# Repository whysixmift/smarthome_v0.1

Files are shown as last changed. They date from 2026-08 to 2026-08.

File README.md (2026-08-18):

# Smart Home ESP32 Board

I wanted to control lights and appliances in my room over Wi-Fi without having loose relay modules, breadboards, and 220V AC wires floating around my desk. Wiring loose AC mains on a breadboard felt super unsafe, so I designed this 4-channel relay board in KiCad.

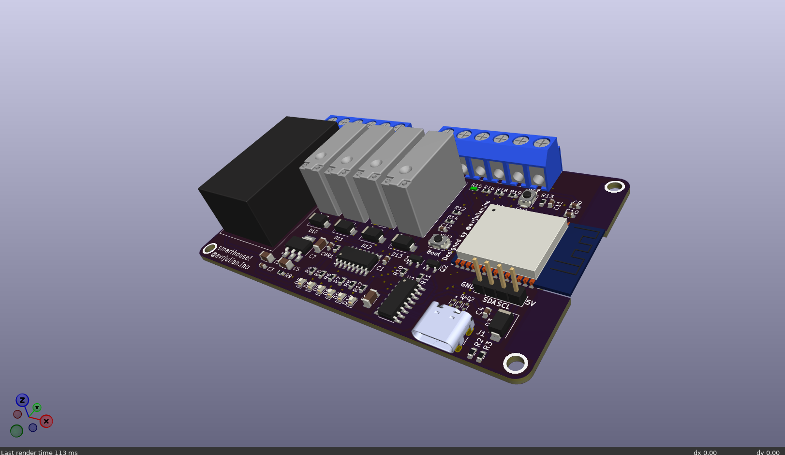
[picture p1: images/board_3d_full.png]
3D view

*3D render of the board in KiCad*

## Features

- **ESP32-WROOM-32**: Main microcontroller for Wi-Fi control.
- **4 Relays**: Switches 4 separate AC/DC loads (5V 5A relays driven by a ULN2003A driver chip).
- **Onboard Power**: Hi-Link HLK-PM01 takes 100-240V AC input and outputs 5V DC, so I don't need an external power adapter. An AMS1117-3.3 steps it down to 3.3V for the ESP32.
- **USB-C Flashing**: Built-in CH340C serial chip with auto-reset circuit so code uploads straight over USB-C.
- **Wall Switch Inputs**: Screw terminal `J3` lets me plug in external wall switches.
- **I2C Header**: 4-pin header `J4` for extra I2C sensors if needed later.

## Pin Map

| ESP32 Pin | Connected To | What It Does |
| :--- | :--- | :--- |
| GPIO 25 | Relay 1 + LED D6 | Relay 1 Output |
| GPIO 23 | Relay 2 + LED D7 | Relay 2 Output |
| GPIO 19 | Relay 3 + LED D8 | Relay 3 Output |
| GPIO 18 | Relay 4 + LED D9 | Relay 4 Output |
| GPIO 13 | Terminal J3 Pin 1 | Wall Switch 1 Input |
| GPIO 12 | Terminal J3 Pin 2 | Wall Switch 2 Input |
| GPIO 27 | Terminal J3 Pin 3 | Wall Switch 3 Input |
| GPIO 14 | Terminal J3 Pin 4 | Wall Switch 4 Input |
| GPIO 21 | Header J4 Pin 3 | I2C SDA |
| GPIO 22 | Header J4 Pin 4 | I2C SCL |
| GPIO 2 | LED D5 | Status LED |
| GPIO 0 | Button SW2 | Boot button |
| EN | Button SW1 | Reset button |

## Board Pictures

### Schematic
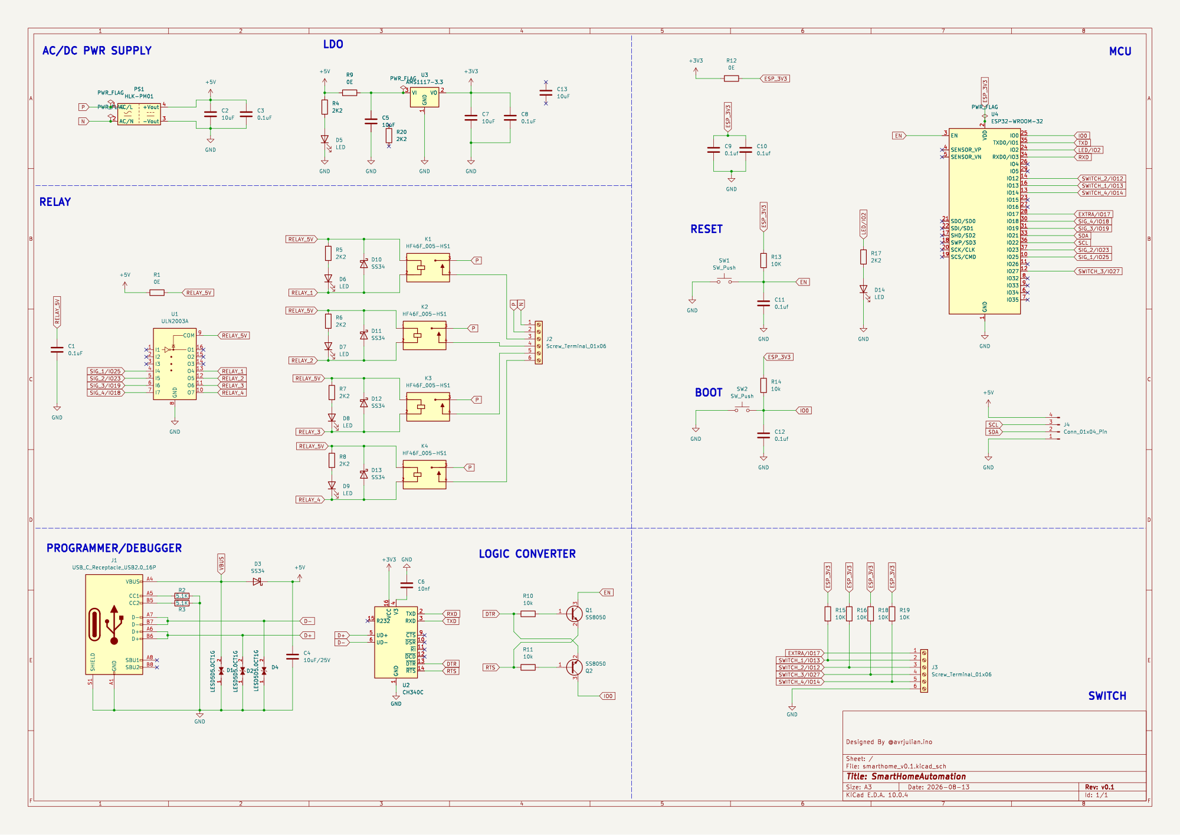
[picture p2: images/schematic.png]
Schematic

*KiCad schematic*

### PCB
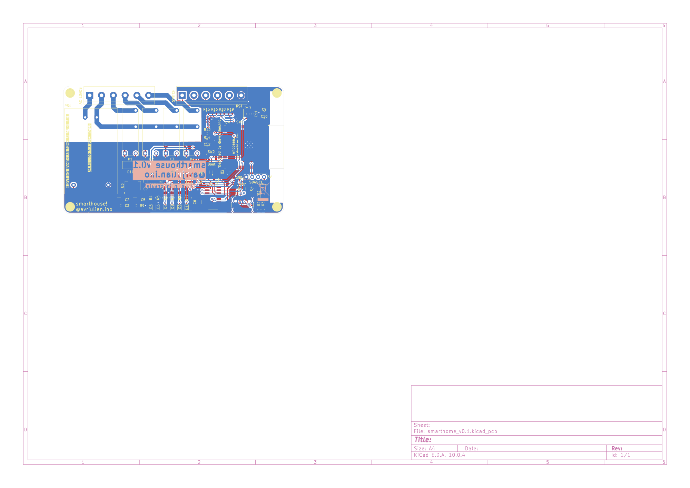
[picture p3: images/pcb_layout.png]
PCB Layout

*PCB layout*

### Details
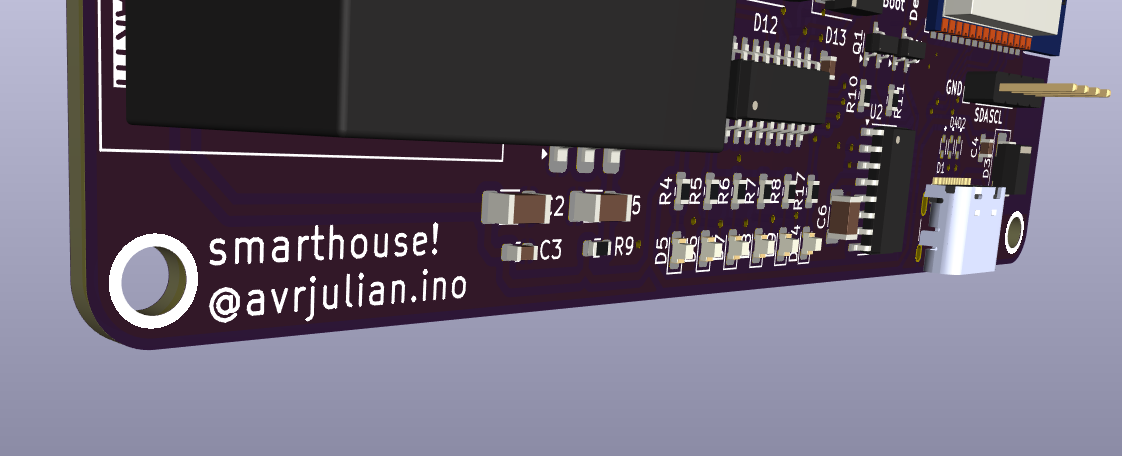
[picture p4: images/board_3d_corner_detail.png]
LEDs

*Status LEDs and passives*

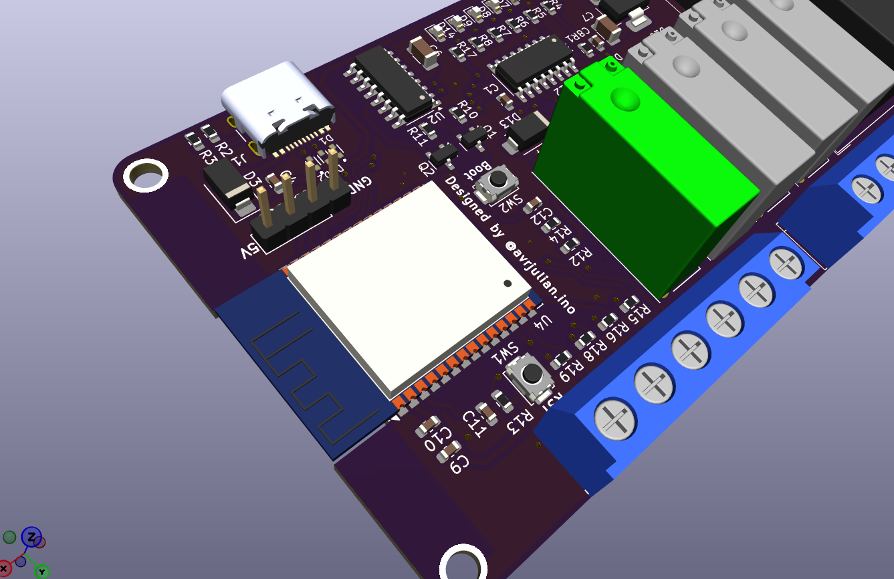
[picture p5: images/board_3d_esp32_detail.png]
ESP32

*ESP32 and USB-C section*

## Firmware

Firmware is inside the `firmware/` folder. It uses PlatformIO with Arduino framework and simple FreeRTOS tasks to read the wall switches and toggle relays.

To flash:
1. Open `firmware/` in VS Code with PlatformIO.
2. Plug in the board over USB-C.
3. Run `pio run -t upload`.

## BOM & Cost

Full component list with purchase links is in [`BOM.csv`](BOM.csv). Total cost is around **$9.36**.

| Part | Qty | Link |
| :--- | :---: | :--- |
| ESP32-WROOM-32 | 1 | [LCSC C82899](https://www.lcsc.com/product-detail/WiFi-Modules_Espressif-Systems-ESP32-WROOM-32-N4_C82899.html) |
| HF46F 5V Relays | 4 | [LCSC C38573](https://www.lcsc.com/product-detail/Relays_Hongfa-America-HF46F-005-HS1_C38573.html) |
| ULN2003A Driver | 1 | [LCSC C14881](https://www.lcsc.com/product-detail/Darlington-Transistor-Arrays_STMicroelectronics-ULN2003D1013TR_C14881.html) |
| HLK-PM01 AC-DC | 1 | [LCSC C209743](https://www.lcsc.com/product-detail/Power-Modules_Hi-Link-HLK-PM01_C209743.html) |
| CH340C Serial | 1 | [LCSC C84681](https://www.lcsc.com/product-detail/USB-Drivers-Receivers-Transceivers_WCH-Jiangsu-Qinheng-Microelec-CH340C_C84681.html) |
| USB-C Connector | 1 | [LCSC C165948](https://www.lcsc.com/product-detail/USB-Connectors_HCTL-HC-TYPE-C-16P-01A_C165948.html) |
| Screw Terminals | 2 | [LCSC C8456](https://www.lcsc.com/product-detail/Pluggable-System-Terminal-Block_C8456.html) |

## Notes / Honest Status

- All ERC and DRC checks in KiCad pass without errors, and firmware builds fine with `pio run`.
- I haven't tested the firmware on the physical PCB yet since the board hasn't arrived.
- Be careful with AC mains (100-240V) near `PS1` and terminal `J2`. Keep it in an insulated case.

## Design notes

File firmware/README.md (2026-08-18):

# ESP32 Smart Home Controller Firmware

This directory contains the firmware for the **Smart Home ESP32 4-Channel Relay Controller** PCB.

## Features

* **4-Channel Relay Control**: Controls four 5V mechanical relays on GPIO 25, 23, 19, and 18 via ULN2003A driver.
* **External Switch Handling**: Debounced digital input handlers for wall switches connected to screw terminal `J3` (GPIO 13, 12, 27, 14).
* **FreeRTOS Multi-Tasking**: Separate tasks for input debouncing and status LED heartbeat animation.
* **Serial Debugging**: Clean boot sequence messages at 115200 baud.

## Hardware GPIO Mapping

| Function | ESP32 GPIO | Net Name | Description |
| :--- | :--- | :--- | :--- |
| **Relay 1** | GPIO 25 | `SIG_1/IO25` | Output 1 (Relay K1 + Status LED D6) |
| **Relay 2** | GPIO 23 | `SIG_2/IO23` | Output 2 (Relay K2 + Status LED D7) |
| **Relay 3** | GPIO 19 | `SIG_3/IO19` | Output 3 (Relay K3 + Status LED D8) |
| **Relay 4** | GPIO 18 | `SIG_4/IO18` | Output 4 (Relay K4 + Status LED D9) |
| **Switch 1** | GPIO 13 | `SWITCH_1/IO13` | Terminal Block J3 Pin 1 |
| **Switch 2** | GPIO 12 | `SWITCH_2/IO12` | Terminal Block J3 Pin 2 |
| **Switch 3** | GPIO 27 | `SWITCH_3/IO27` | Terminal Block J3 Pin 3 |
| **Switch 4** | GPIO 14 | `SWITCH_4/IO14` | Terminal Block J3 Pin 4 |
| **Status LED**| GPIO 2 | `LED/IO2` | Onboard Indicator LED D5 |

## Compilation & Flashing

### Using PlatformIO

```bash
pio run -t upload
```

### Using Arduino IDE

1. Open `firmware.ino` in Arduino IDE.
2. Select Board: **ESP32 Dev Module**.
3. Click **Upload**.

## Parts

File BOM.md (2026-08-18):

# Bill of Materials (BOM) - Smart Home ESP32 Controller

Below is the complete component list for the Smart Home ESP32 4-Channel Relay PCB with direct purchase links (LCSC) and datasheet references.

| Reference | Component | Package / Footprint | Qty | Function | Part Number / Purchase Link | Datasheet |
| :--- | :--- | :--- | :---: | :--- | :--- | :--- |
| `U4` | ESP32-WROOM-32 | ESP32-WROOM-32 SMD | 1 | Microcontroller (Wi-Fi + BLE) | [LCSC C82899](https://www.lcsc.com/product-detail/WiFi-Modules_Espressif-Systems-ESP32-WROOM-32-N4_C82899.html) | [Datasheet](https://www.espressif.com/sites/default/files/documentation/esp32-wroom-32_datasheet_en.pdf) |
| `PS1` | HLK-PM01 | Converter_ACDC:HLK-PMxx | 1 | AC 100-240V to DC 5V 3W Power Module | [LCSC C209743](https://www.lcsc.com/product-detail/Power-Modules_Hi-Link-HLK-PM01_C209743.html) | [Datasheet](http://www.hlktech.net/product_detail.php?id=38) |
| `U3` | AMS1117-3.3 | SOT-223-3 | 1 | 3.3V 1A LDO Voltage Regulator | [LCSC C6186](https://www.lcsc.com/product-detail/Linear-Voltage-Regulators-LDO_Advanced-Monolithic-Systems-AMS1117-3-3_C6186.html) | [Datasheet](http://www.advanced-monolithic.com/pdf/ds1117.pdf) |
| `U1` | ULN2003A | SOIC-16 | 1 | 7-NPN Darlington Transistor Array | [LCSC C14881](https://www.lcsc.com/product-detail/Darlington-Transistor-Arrays_STMicroelectronics-ULN2003D1013TR_C14881.html) | [Datasheet](https://www.ti.com/lit/ds/symlink/uln2003a.pdf) |
| `U2` | CH340C | SOIC-16 | 1 | USB-to-UART Serial Converter | [LCSC C84681](https://www.lcsc.com/product-detail/USB-Drivers-Receivers-Transceivers_WCH-Jiangsu-Qinheng-Microelec-CH340C_C84681.html) | [Datasheet](https://www.sparkfun.com/datasheets/IC/CH340DS1.PDF) |
| `K1, K2, K3, K4` | HF46F-005-HS1 | RELAY_HF46F_005-HS1 | 4 | 5V Coil / 5A 250VAC Mini Power Relays | [LCSC C38573](https://www.lcsc.com/product-detail/Relays_Hongfa-America-HF46F-005-HS1_C38573.html) | [Datasheet](https://www.hongfa.com/Product/PDF/HF46F_en.pdf) |
| `J1` | USB_C_Receptacle_16P | USB-C 16-Pin SMD | 1 | USB Type-C Power & Programming Port | [LCSC C165948](https://www.lcsc.com/product-detail/USB-Connectors_HCTL-HC-TYPE-C-16P-01A_C165948.html) | [Datasheet](https://www.lcsc.com/product-detail/USB-Connectors_HCTL-HC-TYPE-C-16P-01A_C165948.html) |
| `J2, J3` | Screw_Terminal_01x06 | 6-Pin 5.08mm Pitch | 2 | High-Voltage & Relay Screw Terminals | [LCSC C8456](https://www.lcsc.com/product-detail/Pluggable-System-Terminal-Block_C8456.html) | [Datasheet](https://www.lcsc.com/product-detail/Pluggable-System-Terminal-Block_C8456.html) |
| `J4` | Conn_01x04_Pin | PinHeader 1x4 2.54mm | 1 | I2C Header (5V, GND, SDA, SCL) | [LCSC C37207](https://www.lcsc.com/product-detail/Pin-Header-Female-Header_C37207.html) | [Datasheet](https://www.lcsc.com/product-detail/Pin-Header-Female-Header_C37207.html) |
| `Q1, Q2` | SS8050 | SOT-23 | 2 | NPN BJT Transistors (Auto-Reset) | [LCSC C2146](https://www.lcsc.com/product-detail/Bipolar-Transistors-BJT_SS8050_C2146.html) | [Datasheet](https://datasheet.lcsc.com/lcsc/1810171731_MCC-SS8050-TP_C2146.pdf) |
| `D1, D2, D4` | LESD5D5.0CT1G | SOD-523 | 3 | ESD Protection Diodes (5V) | [LCSC C80415](https://www.lcsc.com/product-detail/TVS_LESD5D5-0CT1G_C80415.html) | [Datasheet](https://datasheet.lcsc.com/lcsc/1811061935_LRC-Leshan-Radio-LESD5D5-0CT1G_C80415.pdf) |
| `D3, D10-D13` | SS34 | SMA (DO-214AC) | 5 | 3A 40V Schottky Diodes | [LCSC C1592](https://www.lcsc.com/product-detail/Schottky-Barrier-Diodes-SBD_SS34_C1592.html) | [Datasheet](https://datasheet.lcsc.com/lcsc/1810181519_MS-SS34_C1592.pdf) |
| `D5-D9, D14` | LED Green / Red | 0603 SMD | 6 | Status & Relay Output LEDs | [LCSC C72043](https://www.lcsc.com/product-detail/Light-Emitting-Diodes-LED_C72043.html) | [Datasheet](https://datasheet.lcsc.com/lcsc/1811151441_Foshan-NationStar-Optoelectronics-NCD0603G1_C72043.pdf) |
| `SW1, SW2` | SKRK / Tactile | 3x6mm SMD Pushbutton | 2 | Reset & Boot Tactile Switches | [LCSC C318884](https://www.lcsc.com/product-detail/Tactile-Switches_C318884.html) | [Datasheet](https://datasheet.lcsc.com/lcsc/1912251636_ALPS-Electric-SKRKAEE010_C318884.pdf) |
| `C1, C3, C8-C12` | 0.1uF 50V | 0603 SMD | 7 | Decoupling Capacitors | [LCSC C14663](https://www.lcsc.com/product-detail/Multilayer-Ceramic-Capacitors-MLCC-SMD-SMT_C14663.html) | [Datasheet](https://datasheet.lcsc.com/lcsc/1811141214_YAGEO-CC0603KRX7R9BB104_C14663.pdf) |
| `C2, C5, C7` | 10uF 25V | 1206 SMD | 3 | Filter Capacitors | [LCSC C13585](https://www.lcsc.com/product-detail/Multilayer-Ceramic-Capacitors-MLCC-SMD-SMT_C13585.html) | [Datasheet](https://datasheet.lcsc.com/lcsc/1811141416_YAGEO-CC1206MKX5R8BB106_C13585.pdf) |
| `C4` | 10uF 25V | 0603 SMD | 1 | Power Line Filter Capacitor | [LCSC C19702](https://www.lcsc.com/product-detail/Multilayer-Ceramic-Capacitors-MLCC-SMD-SMT_C19702.html) | [Datasheet](https://datasheet.lcsc.com/lcsc/1811141416_YAGEO-CC0603KRX5R8BB106_C19702.pdf) |
| `C6` | 10nF 50V | 1206 SMD | 1 | Noise Suppression Capacitor | [LCSC C1588](https://www.lcsc.com/product-detail/Multilayer-Ceramic-Capacitors-MLCC-SMD-SMT_C1588.html) | [Datasheet](https://datasheet.lcsc.com/lcsc/1811141214_YAGEO-CC1206KRX7R9BB103_C1588.pdf) |
| `R1, R9, R12` | 0Ω | 0603 SMD | 3 | Zero-Ohm Jumper Resistors | [LCSC C21189](https://www.lcsc.com/product-detail/Chip-Resistor-Surface-Mount_C21189.html) | [Datasheet](https://datasheet.lcsc.com/lcsc/1811141214_Uniroyal-Elec-0603WAF0000T5E_C21189.pdf) |
| `R2, R3` | 5.1kΩ 1% | 0603 SMD | 2 | USB-C CC Line Pull-down Resistors | [LCSC C23186](https://www.lcsc.com/product-detail/Chip-Resistor-Surface-Mount_C23186.html) | [Datasheet](https://datasheet.lcsc.com/lcsc/1811141214_Uniroyal-Elec-0603WAF5101T5E_C23186.pdf) |
| `R4-R8, R17` | 2.2kΩ 1% | 0603 SMD | 6 | LED Current Limiting Resistors | [LCSC C4190](https://www.lcsc.com/product-detail/Chip-Resistor-Surface-Mount_C4190.html) | [Datasheet](https://datasheet.lcsc.com/lcsc/1811141214_Uniroyal-Elec-0603WAF2201T5E_C4190.pdf) |
| `R10, R11, R13-R16, R18, R19` | 10kΩ 1% | 0603 SMD | 8 | Pull-Up / Pull-Down Resistors | [LCSC C25804](https://www.lcsc.com/product-detail/Chip-Resistor-Surface-Mount_C25804.html) | [Datasheet](https://datasheet.lcsc.com/lcsc/1811141214_Uniroyal-Elec-0603WAF1002T5E_C25804.pdf) |

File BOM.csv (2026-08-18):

Component | Quantity | Specification / Part Number | Purpose | Purchase Link | Unit Price ($) | Total Price ($)
ESP32-WROOM-32 | 1 | ESP32-WROOM-32-N4 4MB Flash | Microcontroller (Wi-Fi + BLE) | https://www.lcsc.com/product-detail/WiFi-Modules_Espressif-Systems-ESP32-WROOM-32-N4_C82899.html | 2.75 | 2.75
Hongfa / Songle 5V Relay | 4 | HF46F-005-HS1 5V 5A Mini Power Relay | 5V Mechanical Relays (K1-K4) | https://www.lcsc.com/product-detail/Relays_Hongfa-America-HF46F-005-HS1_C38573.html | 0.45 | 1.80
ULN2003A | 1 | ULN2003ADR SOIC-16 | 7-NPN Darlington Relay Driver IC | https://www.lcsc.com/product-detail/Darlington-Transistor-Arrays_STMicroelectronics-ULN2003D1013TR_C14881.html | 0.18 | 0.18
SSD1306 OLED Display | 1 | 0.96 inch 128x64 I2C OLED Module | Local Display Interface (J4 Header) | https://www.lcsc.com/product-detail/OLED-Displays-Modules_KMR-KMR-0-96-OLED-W_C2836248.html | 1.85 | 1.85
Tactile Push Buttons | 2 | 3x6mm SMD Tactile Switch (SKRK) | Reset (SW1) and Boot (SW2) | https://www.lcsc.com/product-detail/Tactile-Switches_C318884.html | 0.05 | 0.10
HLK-PM01 | 1 | 100-240V AC to 5V DC 3W | Onboard Step-down AC-DC Power Module | https://www.lcsc.com/product-detail/Power-Modules_Hi-Link-HLK-PM01_C209743.html | 2.80 | 2.80
AMS1117-3.3 | 1 | SOT-223 3.3V 1A LDO | Linear Voltage Regulator | https://www.lcsc.com/product-detail/Linear-Voltage-Regulators-LDO_Advanced-Monolithic-Systems-AMS1117-3-3_C6186.html | 0.08 | 0.08
CH340C | 1 | SOIC-16 USB-to-UART Bridge | USB Serial Converter IC | https://www.lcsc.com/product-detail/USB-Drivers-Receivers-Transceivers_WCH-Jiangsu-Qinheng-Microelec-CH340C_C84681.html | 0.32 | 0.32
USB Type-C Connector | 1 | 16-Pin SMD Type-C Receptacle | USB Power & Programming Port (J1) | https://www.lcsc.com/product-detail/USB-Connectors_HCTL-HC-TYPE-C-16P-01A_C165948.html | 0.15 | 0.15
Screw Terminal Blocks | 2 | 6-Pin 5.08mm Pitch Terminal Block | High-Voltage AC & Relay Terminals (J2 J3) | https://www.lcsc.com/product-detail/Pluggable-System-Terminal-Block_C8456.html | 0.35 | 0.70
Pin Header 1x4 | 1 | 2.54mm Female Header 4-Pin | I2C OLED Connection Header (J4) | https://www.lcsc.com/product-detail/Pin-Header-Female-Header_C37207.html | 0.06 | 0.06
SS8050 NPN Transistor | 2 | SOT-23 NPN BJT | Auto-Reset Circuit (Q1 Q2) | https://www.lcsc.com/product-detail/Bipolar-Transistors-BJT_SS8050_C2146.html | 0.02 | 0.04
LESD5D5.0CT1G TVS Diode | 3 | SOD-523 ESD Protection Diode | ESD Protection for USB/Reset (D1 D2 D4) | https://www.lcsc.com/product-detail/TVS_LESD5D5-0CT1G_C80415.html | 0.03 | 0.09
SS34 Schottky Diode | 5 | SMA DO-214AC 3A 40V | Reverse Voltage & Flyback Diodes (D3 D10-D13) | https://www.lcsc.com/product-detail/Schottky-Barrier-Diodes-SBD_SS34_C1592.html | 0.04 | 0.20
SMD LEDs | 6 | 0603 Green/Red SMD LED | Power & Relay Status LEDs (D5-D9 D14) | https://www.lcsc.com/product-detail/Light-Emitting-Diodes-LED_C72043.html | 0.01 | 0.06
SMD Resistors (Assorted) | 18 | 0603 SMD Resistors (0Ω 5.1kΩ 2.2kΩ 10kΩ) | Pull-up / Pull-down / LED Limiting (R1-R19) | https://www.lcsc.com/product-detail/Chip-Resistor-Surface-Mount_C25804.html | 0.005 | 0.09
SMD Capacitors (Assorted) | 12 | 0603 / 1206 MLCC (0.1uF 10uF 10nF) | Filter & Decoupling Capacitors (C1-C12) | https://www.lcsc.com/product-detail/Multilayer-Ceramic-Capacitors-MLCC-SMD-SMT_C14663.html | 0.01 | 0.12
TOTAL COST |  |  |  |  |  | $11.21

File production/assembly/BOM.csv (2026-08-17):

Comment | Designator | Footprint | Quantity
0.1uF | C1 | Capacitor_SMD:C_0603_1608Metric | 1
10uF | C2 | Capacitor_SMD:C_1206_3216Metric | 1
0.1uF | C3 | Capacitor_SMD:C_0603_1608Metric | 1
10uF/25V | C4 | Capacitor_SMD:C_0603_1608Metric | 1
10uF | C5 | Capacitor_SMD:C_1206_3216Metric | 1
10nf | C6 | Capacitor_SMD:C_1206_3216Metric | 1
10uF | C7 | Capacitor_SMD:C_1206_3216Metric | 1
0.1uF | C8 | Capacitor_SMD:C_0603_1608Metric | 1
0.1uf | C9 | Capacitor_SMD:C_0603_1608Metric | 1
0.1uf | C10 | Capacitor_SMD:C_0603_1608Metric | 1
0.1uf | C11 | Capacitor_SMD:C_0603_1608Metric | 1
0.1uf | C12 | Capacitor_SMD:C_0603_1608Metric | 1
LESD5D5.0CT1G | D1 | LESD5D5.0CT1G:TVS_LESD5D5.0CT1G | 1
LESD5D5.0CT1G | D2 | LESD5D5.0CT1G:TVS_LESD5D5.0CT1G | 1
SS34 | D3 | Diode_SMD:D_SMA | 1
LESD5D5.0CT1G | D4 | LESD5D5.0CT1G:TVS_LESD5D5.0CT1G | 1
LED | D5 | LED_SMD:LED_0603_1608Metric | 1
LED | D6 | LED_SMD:LED_0603_1608Metric | 1
LED | D7 | LED_SMD:LED_0603_1608Metric | 1
LED | D8 | LED_SMD:LED_0603_1608Metric | 1
LED | D9 | LED_SMD:LED_0603_1608Metric | 1
SS34 | D10 | Diode_SMD:D_SMA | 1
SS34 | D11 | Diode_SMD:D_SMA | 1
SS34 | D12 | Diode_SMD:D_SMA | 1
SS34 | D13 | Diode_SMD:D_SMA | 1
LED | D14 | LED_SMD:LED_0603_1608Metric | 1
USB_C_Receptacle_USB2.0_16P | J1 | lib:USB_C_Receptacle_HCTL_HC-TYPE-C-16P-01A | 1
Screw_Terminal_01x06 | J2 | lib:TerminalBlock_bornier-6_P5.08mm | 1
Screw_Terminal_01x06 | J3 | lib:TerminalBlock_bornier-6_P5.08mm | 1
Conn_01x04_Pin | J4 | Connector_PinHeader_2.54mm:PinHeader_1x04_P2.54mm_Vertical | 1
HF46F_005-HS1 | K1 | HF46F_005-HS1:RELAY_HF46F_005-HS1 | 1
HF46F_005-HS1 | K2 | HF46F_005-HS1:RELAY_HF46F_005-HS1 | 1
HF46F_005-HS1 | K3 | HF46F_005-HS1:RELAY_HF46F_005-HS1 | 1
HF46F_005-HS1 | K4 | HF46F_005-HS1:RELAY_HF46F_005-HS1 | 1
HLK-PM01 | PS1 | Converter_ACDC:Converter_ACDC_Hi-Link_HLK-PMxx | 1
SS8050 | Q1 | Package_TO_SOT_SMD:SOT-23 | 1
SS8050 | Q2 | Package_TO_SOT_SMD:SOT-23 | 1
0E | R1 | Resistor_SMD:R_0603_1608Metric | 1
5.1K | R2 | Resistor_SMD:R_0603_1608Metric | 1
5.1K | R3 | Resistor_SMD:R_0603_1608Metric | 1
2K2 | R4 | Resistor_SMD:R_0603_1608Metric | 1
2K2 | R5 | Resistor_SMD:R_0603_1608Metric | 1
2K2 | R6 | Resistor_SMD:R_0603_1608Metric | 1
2K2 | R7 | Resistor_SMD:R_0603_1608Metric | 1
2K2 | R8 | Resistor_SMD:R_0603_1608Metric | 1
0E | R9 | Resistor_SMD:R_0603_1608Metric | 1
10k | R10 | Resistor_SMD:R_0603_1608Metric | 1
10k | R11 | Resistor_SMD:R_0603_1608Metric | 1
0E | R12 | Resistor_SMD:R_0603_1608Metric | 1
10K | R13 | Resistor_SMD:R_0603_1608Metric | 1
10k | R14 | Resistor_SMD:R_0603_1608Metric | 1
10K | R15 | Resistor_SMD:R_0603_1608Metric | 1
10K | R16 | Resistor_SMD:R_0603_1608Metric | 1
2K2 | R17 | Resistor_SMD:R_0603_1608Metric | 1
10K | R18 | Resistor_SMD:R_0603_1608Metric | 1
10K | R19 | Resistor_SMD:R_0603_1608Metric | 1
SW_Push | SW1 | Button_Switch_SMD:SW_Push_SPST_NO_Alps_SKRK | 1
SW_Push | SW2 | Button_Switch_SMD:SW_Push_SPST_NO_Alps_SKRK | 1
ULN2003A | U1 | Package_SO:SOIC-16_3.9x9.9mm_P1.27mm | 1
CH340C | U2 | Package_SO:SOIC-16_3.9x9.9mm_P1.27mm | 1
AMS1117-3.3 | U3 | Package_TO_SOT_SMD:SOT-223-3_TabPin2 | 1
ESP32-WROOM-32 | U4 | RF_Module:ESP32-WROOM-32 | 1

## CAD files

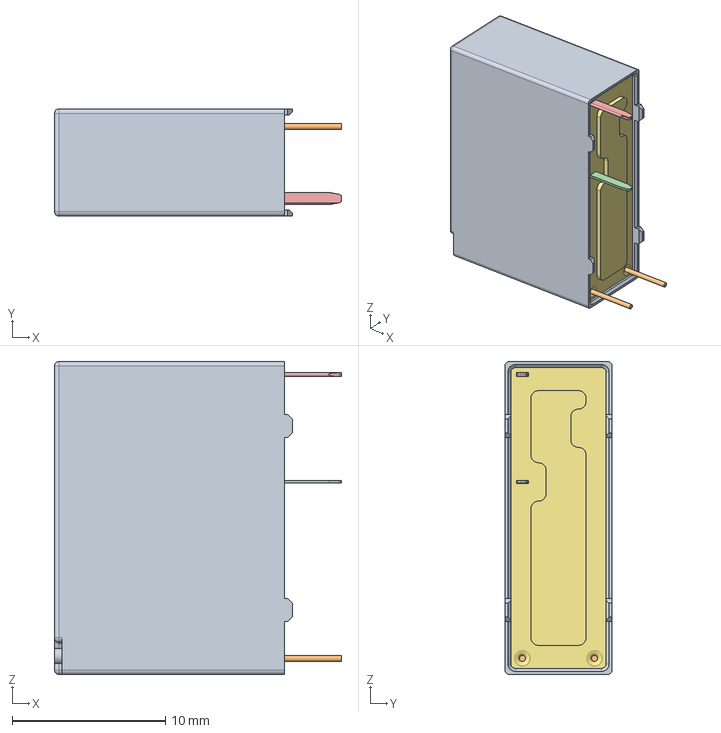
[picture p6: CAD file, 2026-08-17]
3D/189276954-3-hf46f/HF46F.stp
18.7 x 7.00 x 20.4 mm

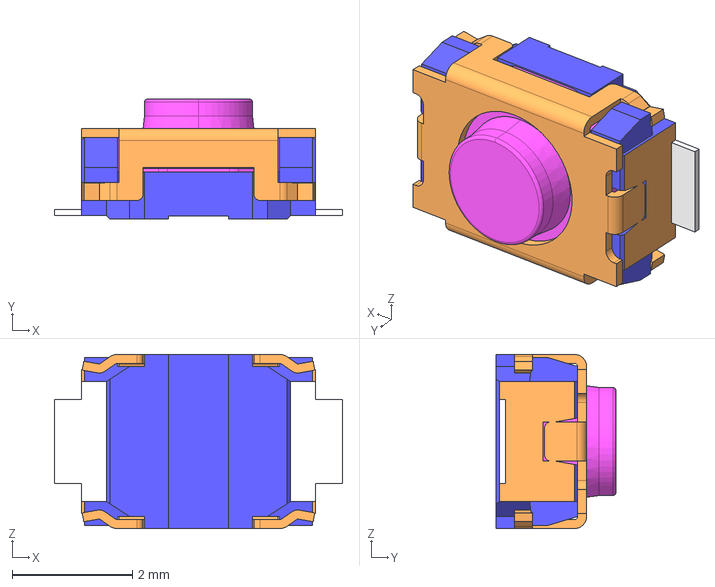
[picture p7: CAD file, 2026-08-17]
3D/skrkaee010.stp
4.80 x 2.00 x 2.90 mm

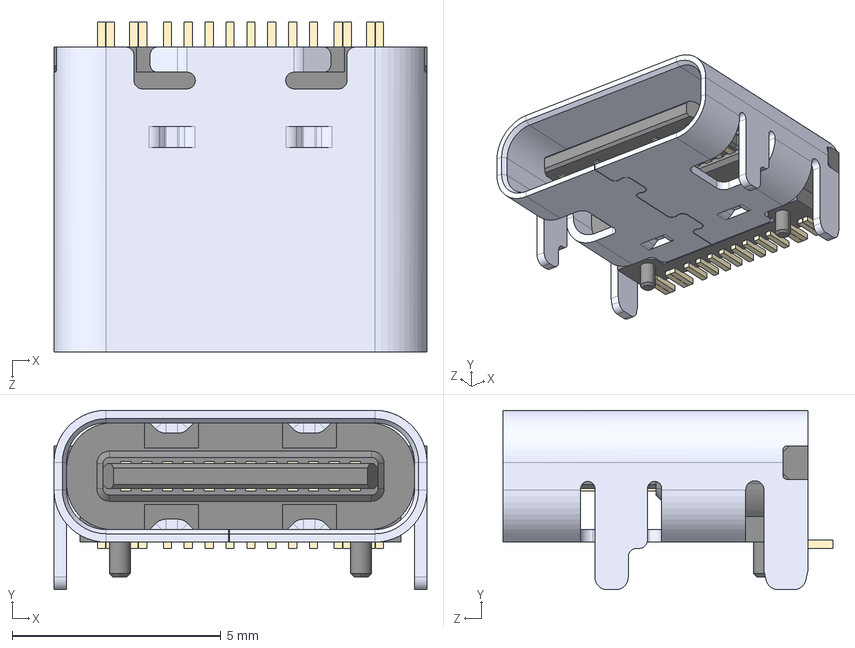
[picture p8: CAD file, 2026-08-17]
3D/TYPE-C-31-M-12--3DModel-STEP-56544.step
8.94 x 4.30 x 7.90 mm

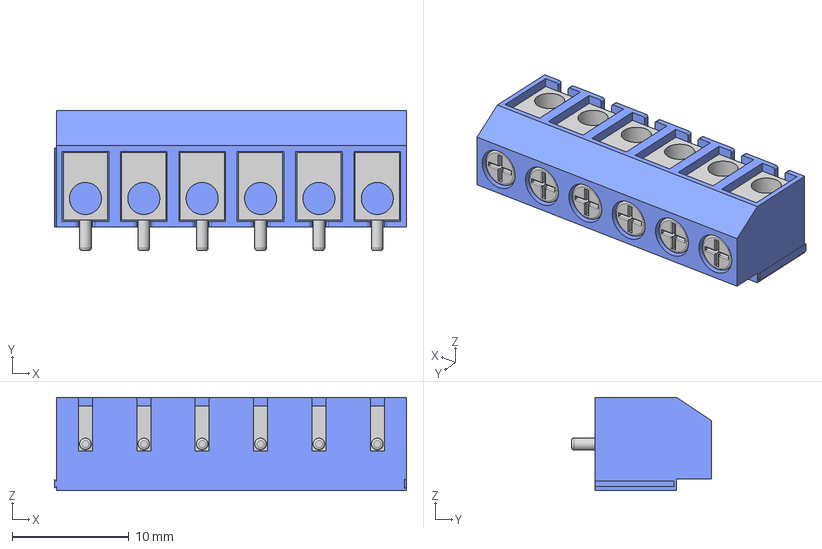
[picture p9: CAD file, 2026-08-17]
3D/Screw Terminal Block 5mm Blue 6-way.step
30.1 x 12.0 x 8.00 mm

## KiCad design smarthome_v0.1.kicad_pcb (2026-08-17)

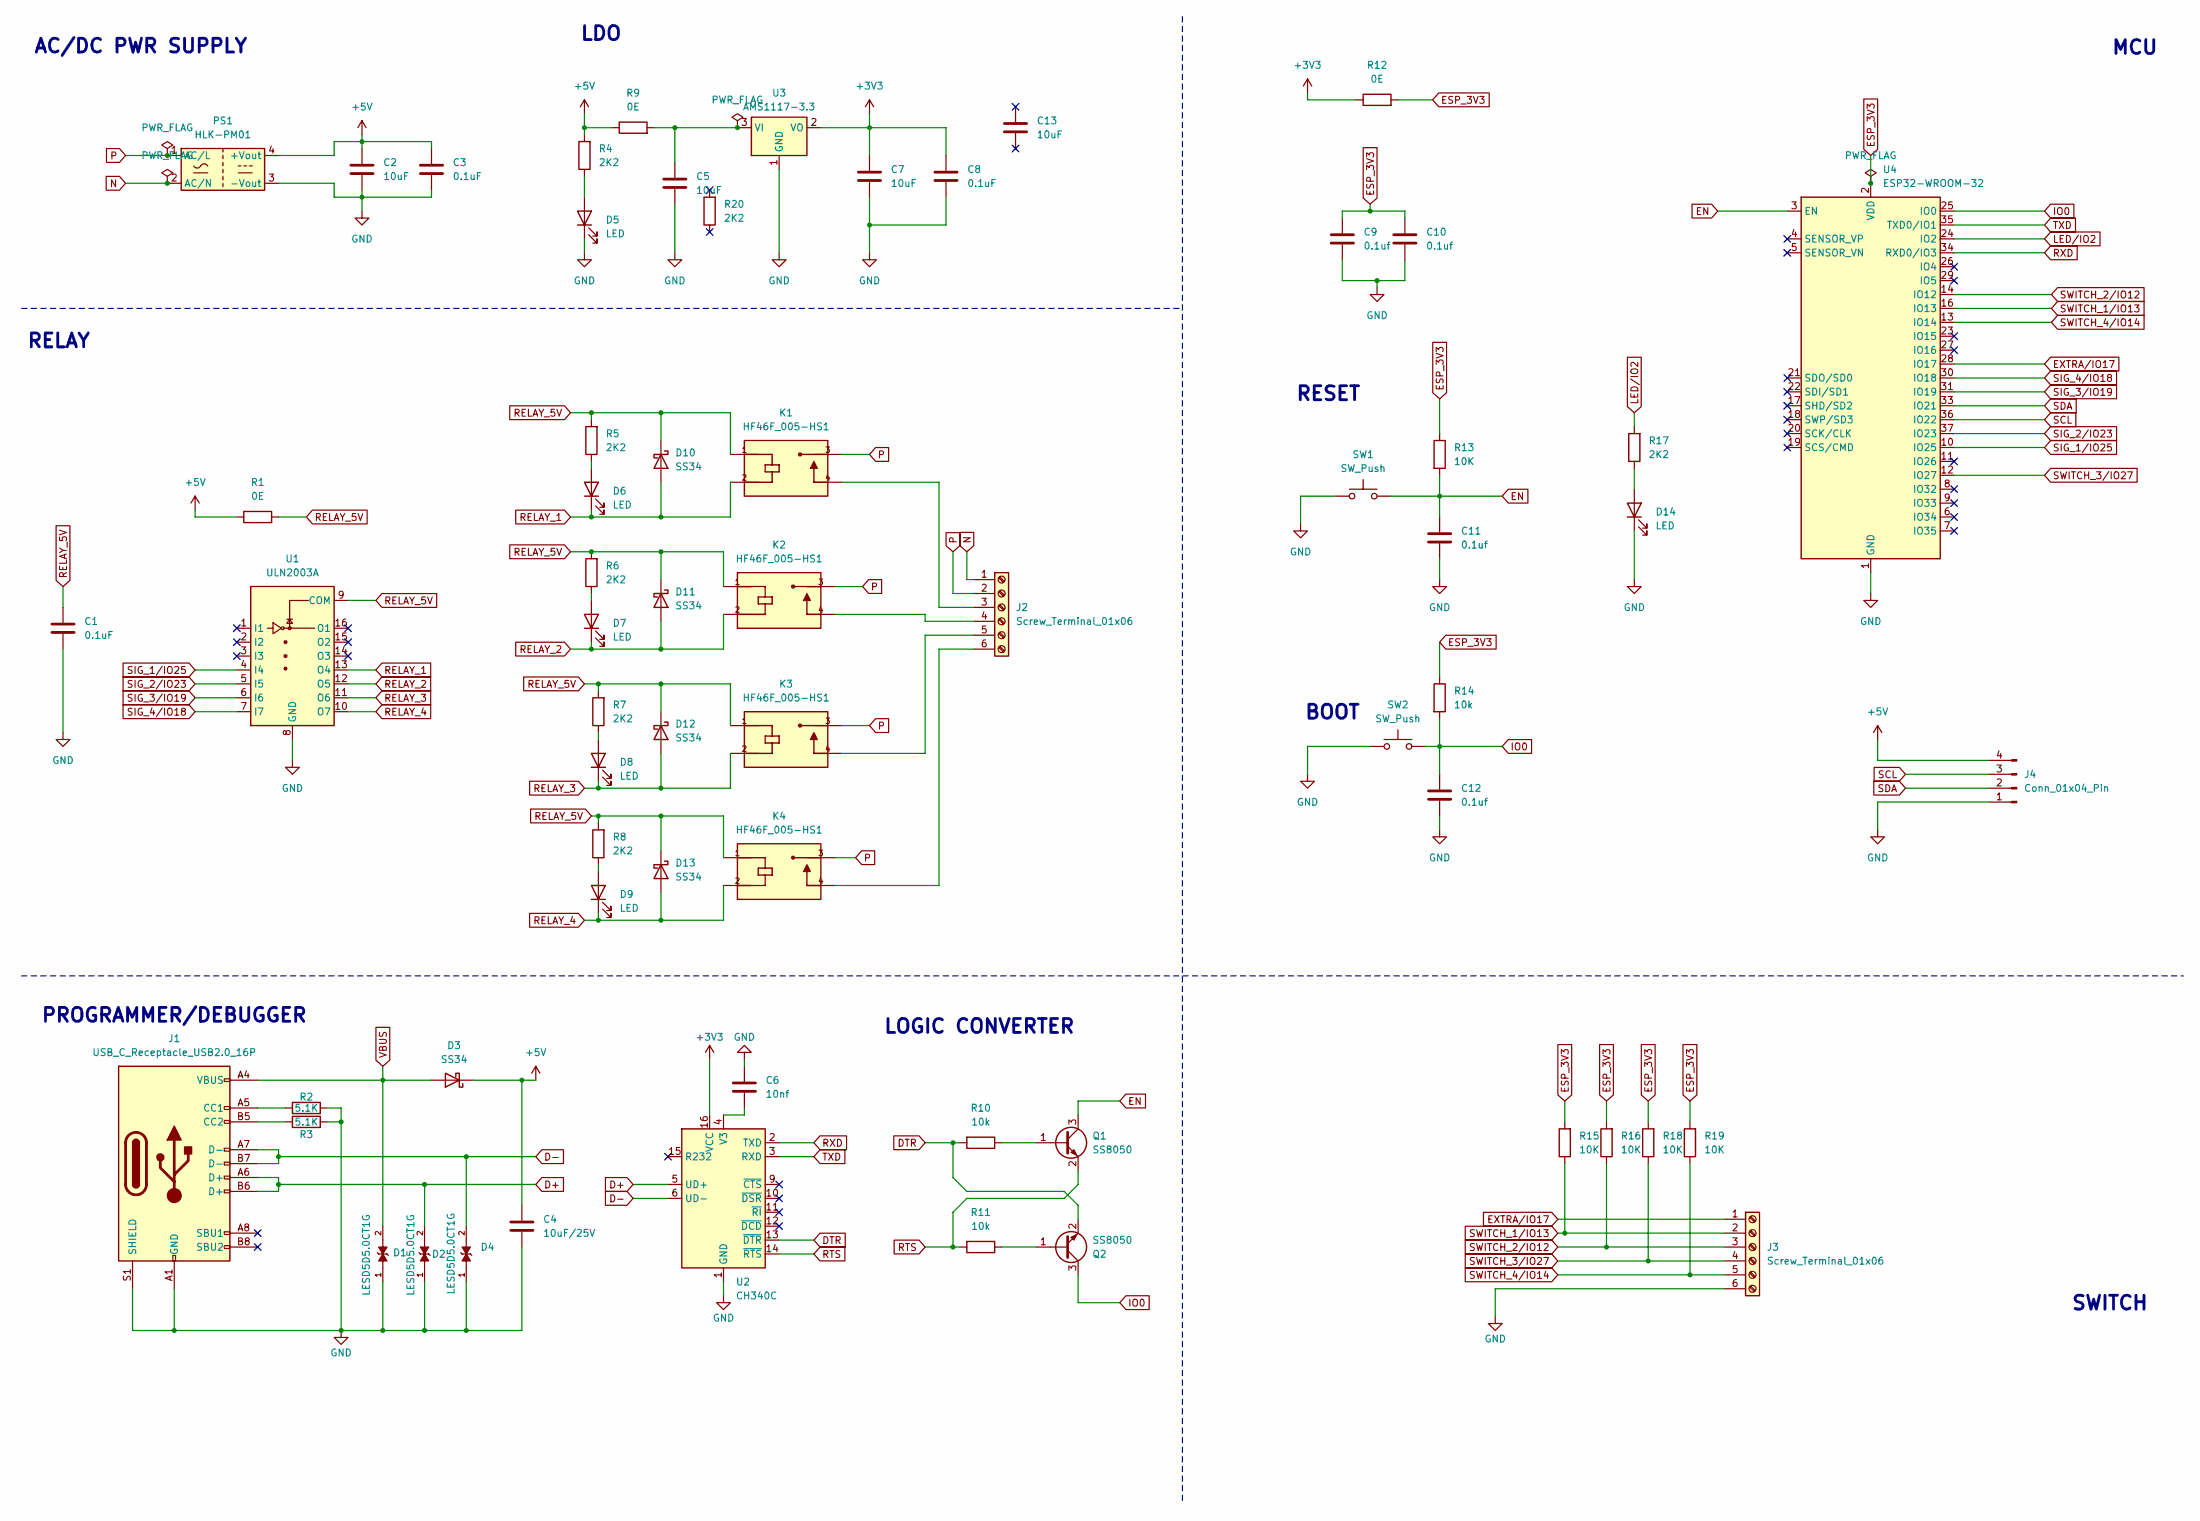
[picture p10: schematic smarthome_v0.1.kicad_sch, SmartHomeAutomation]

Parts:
C1, C3, C8: 0.1uF; C_0603_1608Metric
C2, C5, C7, C13: 10uF; C_1206_3216Metric
C4: 10uF/25V; C_0603_1608Metric
C6: 10nf; C_1206_3216Metric
C9, C10, C11, C12: 0.1uf; C_0603_1608Metric
D1, D2, D4: LESD5D5.0CT1G; TVS_LESD5D5.0CT1G; PARTREV O
D3, D10, D11, D12, D13: SS34; D_SMA
D5, D6, D7, D8, D9, D14: LED; LED_0603_1608Metric
J1: USB_C_Receptacle_USB2.0_16P; USB_C_Receptacle_HCTL_HC-TYPE-C-16P-01A
J2, J3: Screw_Terminal_01x06; TerminalBlock_bornier-6_P5.08mm
J4: Conn_01x04_Pin; PinHeader_1x04_P2.54mm_Vertical
K1, K2, K3, K4: HF46F_005-HS1; RELAY_HF46F_005-HS1; PARTREV 1.00
PS1: HLK-PM01; Converter_ACDC_Hi-Link_HLK-PMxx
Q1, Q2: SS8050; SOT-23
R1, R9, R12: 0E; R_0603_1608Metric
R2, R3: 5.1K; R_0603_1608Metric
R4, R5, R6, R7, R8, R17, R20: 2K2; R_0603_1608Metric
R10, R11, R14: 10k; R_0603_1608Metric
R13, R15, R16, R18, R19: 10K; R_0603_1608Metric
SW1, SW2: SW_Push; SW_Push_SPST_NO_Alps_SKRK
U1: ULN2003A; SOIC-16_3.9x9.9mm_P1.27mm
U2: CH340C; SOIC-16_3.9x9.9mm_P1.27mm
U3: AMS1117-3.3; SOT-223-3_TabPin2
U4: ESP32-WROOM-32

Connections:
+5V: C2.1, C3.1, C4.1, D3.1 (K), J4.4, PS1.4 (+Vout), R1.1, R4.2, R9.1
D+: D2.2, J1.A6 (D+), J1.B6 (D+), U2.5 (UD+)
D-: D4.2, J1.A7 (D-), J1.B7 (D-), U2.6 (UD-)
DTR: Q2.2 (E), R10.2, U2.13 (~DTR)
EN: C11.1, Q1.3 (C), R13.2, SW1.2, U4.3 (EN)
ESP_3V3: C9.1, C10.1, R12.2, R13.1, R14.1, R15.2, R16.2, R18.2, R19.2, U4.2 (VDD)
EXTRA/IO17: J3.1, U4.28 (IO17)
GND: C1.2, C2.2, C3.2, C4.2, C5.2, C6.1, C7.2, C8.2, C9.2, C10.2, C11.2, C12.2, D1.1, D2.1, D4.1, D5.1 (K), D14.1 (K), J1.A1 (GND), J1.A12 (GND), J1.B1 (GND), J1.B12 (GND), J1.S1 (SHIELD), J3.6, J4.1, PS1.3 (-Vout), R2.2, R3.2, SW1.1, SW2.1, U1.8 (GND), U2.1 (GND), U3.1 (GND), U4.1 (GND), U4.15 (GND), U4.38 (GND), U4.39 (GND)
IO0: C12.1, Q2.3 (C), R14.2, SW2.2, U4.25 (IO0)
LED/IO2: R17.2, U4.24 (IO2)
N: J2.1, PS1.2 (AC/N)
unnamed: D5.2 (A), R4.1
unnamed: D6.2 (A), R5.1
unnamed: D7.2 (A), R6.1
unnamed: D8.2 (A), R7.1
unnamed: D9.2 (A), R8.1
unnamed: D14.2 (A), R17.1
unnamed: J1.A5 (CC1), R2.1
unnamed: J1.B5 (CC2), R3.1
unnamed: J2.3, K1.4
unnamed: J2.4, K2.4
unnamed: J2.5, K3.4
unnamed: J2.6, K4.4
unnamed: Q1.1 (B), R10.1
unnamed: Q2.1 (B), R11.1
unnamed: C6.2, U2.4 (V3)
unnamed: C5.1, R9.2, U3.3 (VI)
P: J2.2, K1.3, K2.3, K3.3, K4.3, PS1.1 (AC/L)
RELAY_1: D6.1 (K), D10.2 (A), K1.2, U1.13 (O4)
RELAY_2: D7.1 (K), D11.2 (A), K2.2, U1.12 (O5)
RELAY_3: D8.1 (K), D12.2 (A), K3.2, U1.11 (O6)
RELAY_4: D9.1 (K), D13.2 (A), K4.2, U1.10 (O7)
RELAY_5V: C1.1, D10.1 (K), D11.1 (K), D12.1 (K), D13.1 (K), K1.1, K2.1, K3.1, K4.1, R1.2, R5.2, R6.2, R7.2, R8.2, U1.9 (COM)
RTS: Q1.2 (E), R11.2, U2.14 (~RTS)
RXD: U2.2 (TXD), U4.34 (RXD0/IO3)
SCL: J4.3, U4.36 (IO22)
SDA: J4.2, U4.33 (IO21)
SIG_1/IO25: U1.4 (I4), U4.10 (IO25)
SIG_2/IO23: U1.5 (I5), U4.37 (IO23)
SIG_3/IO19: U1.6 (I6), U4.31 (IO19)
SIG_4/IO18: U1.7 (I7), U4.30 (IO18)
SWITCH_1/IO13: J3.2, R15.1, U4.16 (IO13)
SWITCH_2/IO12: J3.3, R16.1, U4.14 (IO12)
SWITCH_3/IO27: J3.4, R18.1, U4.12 (IO27)
SWITCH_4/IO14: J3.5, R19.1, U4.13 (IO14)
TXD: U2.3 (RXD), U4.35 (TXD0/IO1)
VBUS: D1.2, D3.2 (A), J1.A4 (VBUS), J1.A9 (VBUS), J1.B4 (VBUS), J1.B9 (VBUS)

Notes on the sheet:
BOOT
AC/DC PWR SUPPLY
LDO
RESET
PROGRAMMER/DEBUGGER
LOGIC CONVERTER
MCU
SWITCH
RELAY

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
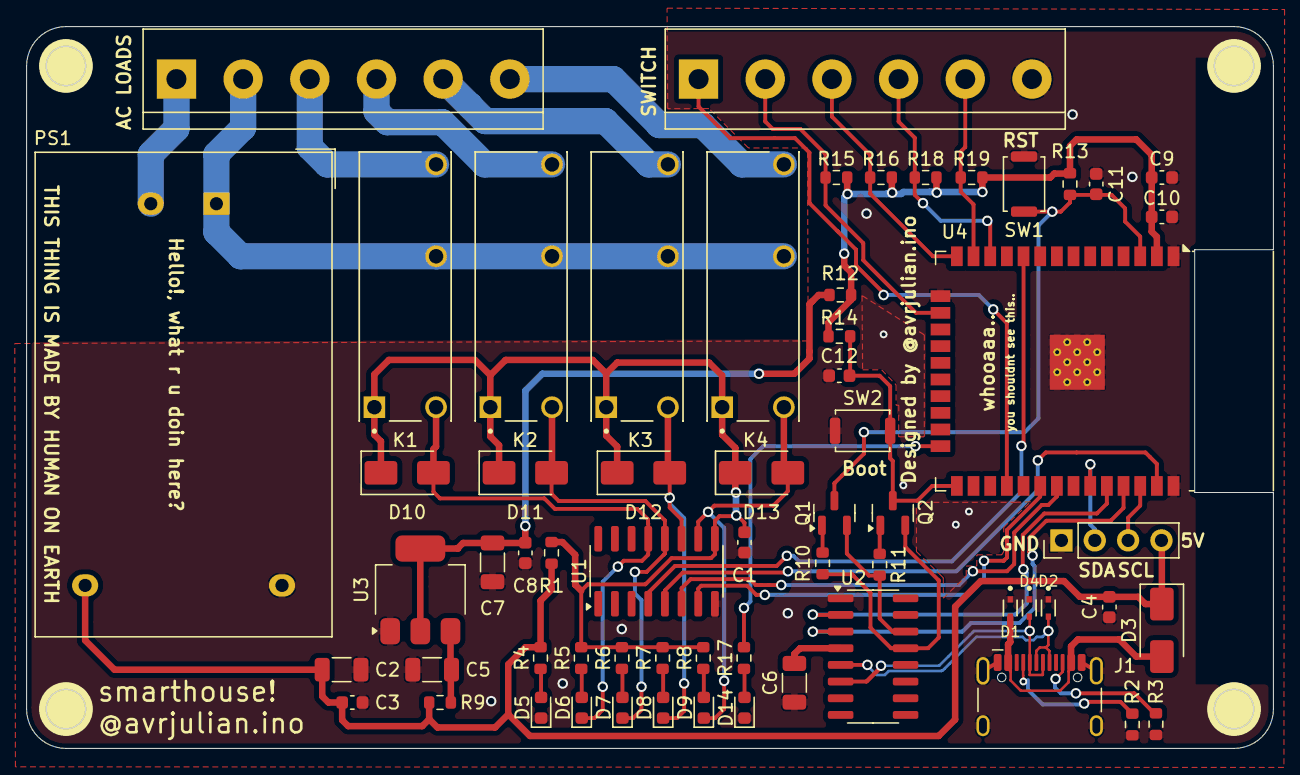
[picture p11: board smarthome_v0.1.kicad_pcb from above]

Board: 2 copper layers, 95.0 x 55.0 mm, 62 parts (0 on the bottom side), 48 nets.

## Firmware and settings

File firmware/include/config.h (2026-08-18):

#ifndef CONFIG_H
#define CONFIG_H

#include <Arduino.h>

// ==========================================
// HARDWARE PIN ASSIGNMENTS (KiCad Schematic)
// ==========================================

// Relay Driver Outputs (via ULN2003A)
#define RELAY_1_PIN      25  // Channel 1 Relay & Status LED D6
#define RELAY_2_PIN      23  // Channel 2 Relay & Status LED D7
#define RELAY_3_PIN      19  // Channel 3 Relay & Status LED D8
#define RELAY_4_PIN      18  // Channel 4 Relay & Status LED D9
#define NUM_RELAYS       4

// Status & Indicators
#define STATUS_LED_PIN   2   // System Status LED D5
#define BOOT_BUTTON_PIN  0   // Tactile Boot Switch SW2

// External Wall Switch / Digital Inputs
#define SWITCH_1_PIN     13  // Switch Input 1
#define SWITCH_2_PIN     12  // Switch Input 2
#define SWITCH_3_PIN     27  // Switch Input 3
#define SWITCH_4_PIN     14  // Switch Input 4

// I2C Expansion Header (J4)
#define I2C_SDA_PIN      21  // Data
#define I2C_SCL_PIN      22  // Clock

// Auxiliary Expansion GPIO
#define EXTRA_IO_PIN     17  // General Purpose IO

// ==========================================
// DEFAULT NETWORK & SYSTEM SETTINGS
// ==========================================

#define HOSTNAME_PREFIX     "SmartHome-ESP32"
#define DEFAULT_AP_SSID     "ESP32-SmartHome-AP"
#define DEFAULT_AP_PASS     "12345678"

#define HTTP_PORT           80
#define MQTT_PORT           1883
#define DEFAULT_MQTT_TOPIC  "smarthome/esp32"

#define DEBOUNCE_DELAY_MS   50   // Switch debounce time
#define RECONNECT_INTERVAL  5000 // Wi-Fi / MQTT reconnect timer (ms)

#endif // CONFIG_H

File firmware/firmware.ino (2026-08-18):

/*
 * ESP32 Smart Home 4-Channel Relay Controller Firmware
 * Board: ESP32 Dev Module
 * Framework: Arduino IDE / PlatformIO
 *
 * KiCad Schematic Pinout:
 * - Relay 1: GPIO 25
 * - Relay 2: GPIO 23
 * - Relay 3: GPIO 19
 * - Relay 4: GPIO 18
 * - Status LED: GPIO 2
 * - Switch Inputs 1..4 (Terminal Block J3): GPIO 13, 12, 27, 14
 */

#include <Arduino.h>

#define RELAY_1_PIN   25
#define RELAY_2_PIN   23
#define RELAY_3_PIN   19
#define RELAY_4_PIN   18

#define SWITCH_1_PIN  13
#define SWITCH_2_PIN  12
#define SWITCH_3_PIN  27
#define SWITCH_4_PIN  14

#define STATUS_LED_PIN 2

const uint8_t relayPins[4]  = { RELAY_1_PIN, RELAY_2_PIN, RELAY_3_PIN, RELAY_4_PIN };
const uint8_t switchPins[4] = { SWITCH_1_PIN, SWITCH_2_PIN, SWITCH_3_PIN, SWITCH_4_PIN };

bool relayStates[4]  = { false, false, false, false };
bool switchStates[4] = { HIGH, HIGH, HIGH, HIGH };

void toggleRelay(int index) {
    if (index < 0 || index >= 4) return;
    relayStates[index] = !relayStates[index];
    digitalWrite(relayPins[index], relayStates[index] ? HIGH : LOW);
    
    Serial.print("Relay ");
    Serial.print(index + 1);
    Serial.println(relayStates[index] ? " ON" : " OFF");
}

void setup() {
    Serial.begin(115200);
    delay(200);

    Serial.println("Smart Home PCB");
    Serial.println("Firmware: 0.1");

    for (int i = 0; i < 4; i++) {
        pinMode(relayPins[i], OUTPUT);
        digitalWrite(relayPins[i], LOW);

        pinMode(switchPins[i], INPUT_PULLUP);
    }

    pinMode(STATUS_LED_PIN, OUTPUT);
    digitalWrite(STATUS_LED_PIN, LOW);

    Serial.println("Ready");
}

void loop() {
    for (int i = 0; i < 4; i++) {
        bool reading = digitalRead(switchPins[i]);
        if (reading != switchStates[i]) {
            switchStates[i] = reading;
            if (reading == LOW) {
                toggleRelay(i);
            }
        }
    }
    delay(30);
}

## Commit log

2026-08-17 Initial commit: KiCad smart home PCB design and fabrication package
    [BOM.csv, HF46F.stp, Screw Terminal Block 5mm Blue 6-way.step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]
2026-08-17 fix: format CPL and BOM CSVs for JLCPCB SMT parser
    [BOM.csv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]
2026-08-17 fix: remove R20 and C13 from BOM to match PCB layout
    [BOM.csv]
2026-08-18 add smart home controls and firmware
    [BOM.csv, smarthome_v0.1.kicad_pcb]
2026-08-18 add navigation switches SW3, SW4, SW5 symbols to schematic
    [smarthome_v0.1.kicad_sch]
2026-08-18 revert PCB and schematic to original design, update BOM and firmware docs
    [BOM.csv, smarthome_v0.1.kicad_pcb, smarthome_v0.1.kicad_sch]
2026-08-18 update README documentation for project overview, GPIO pin map, assembly order, firmware, and BOM
2026-08-18 clean README, BOM, and firmware to strictly match exact physical hardware without OLED or extra switches
